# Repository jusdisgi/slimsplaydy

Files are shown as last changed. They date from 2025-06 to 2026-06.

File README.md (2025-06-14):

# Slim Splaydy

This is the real Slim Splaydy. All the other Slim Splaydies are just imitating.

It's a 34-key split ergo layout with a bit of splay and quite a bit of stagger, using Kailh PG1316S ultra-low-profile switches. The result should be extemely slim. I'm using a nice!nano controller, SMD to the board upside down with a cutout for the components, so it chould only be 1.6mm above the PCB surface. The PCB is also cut away where the battery goes, and the case includes a battery holder, allowing up to a 3.0mm battery. The case also has holes for magnets to sit just below the surface, allowing the two sides to magnetically clasp together for transport. When closed up this way the two halves should come in around 8mm thick.

The design is intended to be very easy to assemble. Fvery component on the board is SMD, and all are on the front side. So it should be buildable in one run on a hot plate. Should not even need a soldering iron!

This repo includes the ergogen config file, kicad PCB and schematic files for both left and right halves, and STEP files of all case pieces. Production files and a build guide will follow once everything is finalized.

Here are some pictures...





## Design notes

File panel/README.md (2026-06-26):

# slimsplaydy — JLCPCB panel (KiKit)

Panelize the **routed** slimsplaydy halves for JLCPCB. This is the **scripted** pipeline ported
from LightFury (which proved out the by-hand merge + `kikit fab --assembly` path was a dead end).
The per-half boards (`slimsplaydy_left/right.kicad_pcb`) are the source of truth; everything below
rebuilds the combined board, panel, and CPL/BOM from them, so re-run it any time a half changes.

> **Supersedes** the old "Option B / KiCad *Append Board*" plan and the hand-merged
> `slimsplaydy_both*` files. Don't use those.

Per-half outline ≈ **122.5 × 97.3 mm**. The halves **stack vertically, interlocked** — the lower
half's top peak tucks into the upper half's battery-slot notch — so the nest is much tighter than a
flat side-by-side. Tune `PITCH_MM` / `XOFF_MM` in `merge_both.py` from the first KiKit preview.

**Environment:** use the **KiCad Command Prompt** (so `python` = KiCad's Python with `pcbnew`).
KiKit's `kikit.exe` installs to `...KiCad\9.0\3rdparty\Python311\Scripts`, which isn't on PATH by
default — add it for the session before the `kikit` commands:

```bat
set PATH=%PATH%;C:\Users\hunte\Documents\KiCad\9.0\3rdparty\Python311\Scripts
```

## Full workflow (in order)

```bash
cd slimsplaydy

# 1. Merge the two halves -> slimsplaydy_both.kicad_pcb. Right-half refs get a _2 suffix,
#    nets get L_/R_ prefixes so the halves stay electrically distinct. Vertical interlocked
#    nest, no rotation/tilt (every part is already on a whole degree). Replaces the by-hand
#    merge. ALSO drops 8 kikit:Tab annotations so the panelizer puts tabs exactly where we want.
#    Tune PITCH_MM / XOFF_MM / TAB_ANNOTATIONS in the script from the Step-2 preview.
python panel/merge_both.py

# 2. Frame it into a panel (full frame; tabs come from the annotations, see preset note below).
kikit panelize -p panel/slimsplaydy_panel.json slimsplaydy_both.kicad_pcb panel/slimsplaydy_panel.kicad_pcb

# 3. Export GERBERS from panel/slimsplaydy_panel.kicad_pcb (open in pcbnew -> Fabrication Toolkit
#    plugin, or KiCad Plot). Use the toolkit for GERBERS ONLY — NOT `kikit fab jlcpcb --assembly`
#    (it needs a schematic the panel's _2 refs can't match) and NOT the toolkit's own CPL/BOM.

# 3b. Copy the toolkit's gerber zip up into the canonical order folder:
cp panel/production/slimsplaydy_panel.zip production-panel/

# 4. Generate the CPL + BOM from the SAME panel file, straight into production-panel/.
python panel/gen_cpl.py panel/slimsplaydy_panel.kicad_pcb production-panel

# 5. LOCAL verification — open these and check BEFORE uploading.
python panel/render_cpl.py panel/slimsplaydy_panel.kicad_pcb production-panel/positions.csv panel/verify
#    verify_overview.png : every red dot must sit on a pad cluster, none off-board
#    verify_parts.png    : every red ring at body center; orange star = our pin-1
```

Upload to JLC: the three files in **`../production-panel/`** — `slimsplaydy_panel.zip` +
`positions.csv` + `bom.csv` (and attach `SlimSplaydy_BlindSlot_Both.png` to the order notes).
Full CPL/BOM rules + the one-time JLC rotation pass live in **`CPL_WORKFLOW.md`**.

## Where things live (after cleanup)

- **`../production-panel/`** — the canonical JLC upload set (gerber zip + `bom.csv` + `positions.csv`
  + blind-slot drawing + its own README). **This is what you order from.**
- **`panel/production/`** — Fabrication Toolkit scratch (gitignored, overwritten each run). Not for ordering.
- **`panel/verify/`** — local placement-check PNGs from `render_cpl.py`.
- **`../old_cruft/`** — superseded test-order files (`Production_JLCPCBA/`, the May `production/`,
  retired `cpl_build/`, `REVIEW-KICKOFF.md`). Kept for reference; don't fab from them.

## Parts (what JLC places)

Per half: **17× PG1316S** (S1–S17), **CONN1** Molex Pico-EZmate, **PWR1** power switch, **RST1**
reset switch. LCSC: EZmate `C505023`, power `C2911519`, reset `C79174`, PG1316S **consigned**
`C9900170245`. **Excluded** (not placed): MCU1 nice!nano (**DNP / hand-soldered**), MH1–15 (NPTH
mounting holes), MAG1 (magsafe silk only). `gen_cpl.py` already enforces all of this.

## The one manual step: confirm rotations (do this ONCE)

Positions are exact (origin = body center = JLC datum). The only thing board geometry can't tell us
is how JLC's library part is oriented vs our footprint. Resolve it in a **single clean pass** — read
JLC's exact values, don't nudge:

1. Upload and open JLC's assembly preview.
2. For each **oriented** part — **CONN1** (Molex `C505023`), **PWR1** (`C2911519`), **RST1**
   (`C79174`) — read whether it needs 0/90/180/270°.
3. Put each into `ROT_CORR` in `gen_cpl.py`, keyed by LCSC, then re-run steps 4–5 (positions are
   unaffected) and re-upload. `C79174` = 90 and `C2911519` = 90 are carried over from LightFury (same
   ceoloide footprints) as starting points — **still confirm them**. `C505023` starts at 0
   (un-confirmed). PG1316S (`C9900170245`) starts at 0.

If a part's *body* ever looks off its pads (not just rotated), add `POS_OVERRIDE[lcsc] = (dx, dy)`
in part-local mm. None expected.

## Blind slot (order note — NOT in these files)

The 0.8 mm back pocket for the steel MagSafe ring is **ordered at JLC**, not in the design files —
add it to the order notes / drawing as before
(`Production_JLCPCBA/SlimSplaydy_BlindSlot_Both.png`). At 0.8 mm depth F.Cu is untouched; B.Cu was
hand-routed clear of the ring — keep it clear on any re-route.

## Preset / gotchas

- **`slimsplaydy_panel.json`**: **annotation** tabs + **full frame** + mouse-bites. `fixed`/`spacing`
  tabs distribute blindly and land on the battery-slot openings (and `spacing` errors on concave
  outlines); annotation tabs put a tab exactly at each `kikit:Tab` marker. Rails 5 mm, mouse-bite
  0.5 mm drill @ 0.8 mm, tooling 1.52 mm, fiducials 1 mm copper / 2 mm opening, 1 mm mill radius,
  `JLCJLCJLCJLC` order token, origin `tl`.
- **Tabs are placed by `merge_both.py`** (`UPPER_TABS` + `LOWER_TABS`): **10 tabs, each half held on
  3 sides** — upper: top (2) + right (2) + left (`GreenL`); lower: left (2) + bottom (2) + right
  (`GreenR`). **Every tab is half→frame; there are NO half-to-half tabs** (fewest connections, and
  each cut is cleanly two-sided). They clear both battery slots and flank both MCU slots. Six sit on
  convex bounding-box edges (short tabs); `GreenL`/`GreenR` reach the concave upper-left / lower-right
  edges and are necessarily longer, because KiKit's partition line follows the bounding box.
  `LOWER_TABS` auto-shift with the nest, so they stay on the lower half when you change
  `PITCH_MM`/`XOFF_MM`. To retune: edit a list (each entry is `(x_mm, y_mm, into-board direction
  E/N/W/S)`), re-run step 1, re-preview. **If a tab doesn't appear, flip its direction 180°** — the
  ray pointed the wrong way. You can also drop `kikit:Tab` footprints by hand in KiCad (lib must be
  literally `kikit`; add a text field `KIKIT: width: 3mm`).
- **Don't let KiKit stitch the halves:** KiKit treats `slimsplaydy_both` as ONE board with two
  disjoint outlines and auto-adds a tab joining the two pieces at their single **closest approach**
  (independent of our annotations) — it shows up as a one-sided-cut bridge at the right shoulder of
  the tuck. The fix is separation: **PITCH 85 / XOFF −17** opens the nearest approach to ~6.6 mm
  (right shoulder ~7.6 mm, was 3.5 mm at PITCH 82) so KiKit leaves them apart. Tuck is still ~12 mm.
  (This also clears the **2 mm router** = 2 × `post.millradius` with room to spare.) If KiKit still
  stitches them at this gap, the definitive fix is the **multiboard** route — a `kikit:Board`
  annotation per half so KiKit treats them as two separate boards and never joins them.
- Tune the nest in `merge_both.py`: `PITCH_MM` (vertical center-to-center; smaller = deeper tuck =
  shorter panel, but watch the nearest-approach so KiKit doesn't stitch) and `XOFF_MM` (slide the
  lower half: more negative opens the right shoulder, less negative opens the left). Currently 85 / −17.
- **Prereq (done):** the per-half `LCSC` fields are filled and pushed to the PCBs, so the BOM carries
  part numbers. Verified: `gen_cpl.py` reads `C505023 / C2911519 / C79174 / C9900170245` straight off
  the boards.
- Gerbers and CPL **always** come from the same `slimsplaydy_panel.kicad_pcb` generation. If you
  re-panelize, re-export both — never mix generations.

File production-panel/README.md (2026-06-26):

# SlimSplaydy — JLCPCB order set

**These files are what you upload to JLCPCB. Nothing else.**

| file | what it is | upload as |
|---|---|---|
| `slimsplaydy_panel.zip` | Gerbers + drill for the full panel (both halves, frame, mouse-bites) | Gerber |
| `bom.csv` | Bill of materials (one line per LCSC part) | BOM |
| `positions.csv` | Pick-and-place / CPL (origin datum, integer rotations, PWR offset applied) | CPL |
| `SlimSplaydy_BlindSlot_Both.png` | Drawing for the 0.8 mm blind back-pocket | attach to **order notes** |

The gerber is uploaded once at the **start** of the order (before PCBA). The BOM/CPL are uploaded
in the PCBA step and can be re-uploaded freely. **You only need a fresh gerber when the copper
changes** (re-panelize or a half edit) — pure rotation/position tweaks ride on the CPL alone.

## What JLC assembles vs. what you do by hand

- **Assembled (40 placements):** 34× PG1316S (S1–S17 ×2, **consigned** reel `C9900170245`),
  2× power switch (`C2911519`), 2× reset switch (`C79174`), 2× Molex Pico-EZmate (`C505023`).
- **NOT assembled (mark DNP / hand-solder):** the **nice!nano** (one per half) — not in JLC's
  library. The mounting holes, MAG1 silk, and fiducials are mechanical/markers, not parts.

## Order notes (don't forget)

- **Blind slot:** mill a **0.8 mm-deep back pocket** (B side) under each MagSafe ring per
  `SlimSplaydy_BlindSlot_Both.png`. It is **not** in the gerbers — request it in the order remarks.
- **PG1316S are consigned** (your reel) — declare them as customer-supplied, not JLC-sourced.
- **nice!nano = DNP**, hand-soldered after.

## Regenerating these

Full procedure + hard rules: [`../panel/CPL_WORKFLOW.md`](../panel/CPL_WORKFLOW.md). Short version,
from the repo root, all from the **same** panel generation:

```bat
:: gerbers: open panel\slimsplaydy_panel.kicad_pcb in KiCad, run the Fabrication Toolkit,
:: then copy its zip up here:
copy panel\production\slimsplaydy_panel.zip production-panel\

:: BOM + CPL straight from the same panel file:
python panel\gen_cpl.py panel\slimsplaydy_panel.kicad_pcb production-panel

:: optional local sanity render (writes PNGs to panel\verify\):
python panel\render_cpl.py panel\slimsplaydy_panel.kicad_pcb production-panel\positions.csv panel\verify
```

Gerbers and CPL **must** come from the same panel generation, or parts land on stale copper.

## Part-specific corrections baked into `gen_cpl.py`

- Rotation (`ROT_CORR`) and position (`POS_OVERRIDE`) tweaks for the oriented parts live at the top
  of `gen_cpl.py`. Current: PWR/RST `C2911519`/`C79174` = **90°**, Molex `C505023` = **0°**,
  PG1316S = 0°; PWR `C2911519` nudged **0.3 mm west** (part-local, so the mirrored half tracks it).
- These rotations are confirmed-by-eye in JLC's assembly preview — see the one-time pass in
  `CPL_WORKFLOW.md` if a half edit ever changes a footprint.

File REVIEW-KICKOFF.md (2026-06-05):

# slimsplaydy — review & optimize: session kickoff

Goal: review the **already-routed** slimsplaydy board, fix only genuine functional problems, and get
it panel-ready for JLCPCB. **Preserve the routing.** Regenerating from ergogen wipes routing (forces a
full re-route), so only do it if a real functional defect requires it.

## Context
- 34-key low-profile splay split; nice!nano (one per half), PG1316S. The original "Slim Splaydy".
- **Parent of `../xiphos`** and shares its design concept — read `../xiphos/CLAUDE.md` "Design concept"
  and "Production" sections; the workspace `../CLAUDE.md` "Schematics, combined boards & production"
  section applies here too.
- Already has a **JLC PCBA test order**: `production/` and `Production_JLCPCBA/` (BOM, CPL, gerbers,
  blind-slot drawings). LCSC: EZmate `C505023`, power `C2911519`, reset `C79174`, PG1316S consigned
  `C9900170245`; nano DNP / hand-soldered.
- Files: routed `slimsplaydy_left.kicad_pcb` / `_right` (+ hand-merged `_both*`), `*.kicad_sch`,
  `config.yaml`, local `footprints/`. (Note: `../xiphos/_old_slimsplaydy/` holds copies xiphos forked
  from — the working repo is here.)
- **No `CLAUDE.md` yet** — create one (model on `../zmk-config-totem/CLAUDE.md`; keep it thin) and fold
  in the shared design concept.

## First steps
1. Read `config.yaml`, the routed PCBs, schematics, and the production BOM/CPL. Write `slimsplaydy/CLAUDE.md`.
2. Sanity-check without re-routing: net/ref consistency, BOM completeness (every part has an LCSC #),
   footprints in sync with `../ergogen-footprints`, and schematic ↔ PCB parity per the
   `Schematics_and_Ergogen.md` workflow.
3. **Structure decision:** xiphos moved to a single combined board + one project + `L_`/`R_` nets. For
   slimsplaydy that rework means re-routing — likely **not** worth it since it's routed and PCBA-tested.
   Default to keeping the current structure; unify only if Hunter asks.
4. **Panelize for JLC with KiKit** (multiboard: rails / mouse-bites / fiducials / tooling, nested to
   minimize the bounding rectangle → lower cost). KiKit runs on Hunter's machine; Claude writes the
   config and picks the nest.
5. Confirm the blind-slot fab notes/drawings are current and traces still clear the slot.

git: hands-off — write the commands, don't run them.

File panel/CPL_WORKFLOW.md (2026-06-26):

# SlimSplaydy CPL / BOM workflow

How to produce a correct JLCPCB pick-and-place (CPL) + BOM for the panel. Ported from LightFury,
which debugged this end-to-end; SlimSplaydy is simpler (no LCD, no encoder, no RESW injection).

## The rule set (proven on LightFury, applies here)

- **Position = footprint origin.** The footprint origin sits at each part's body center, which is
  exactly JLC's placement datum. Never shift to the pad centroid — that drags asymmetric parts
  (the Molex, the switches) off their pads.
- **CPL origin = panel Edge.Cuts top-left, Y flipped** — the same frame KiCad/the Fabrication
  Toolkit plots the gerbers in, so CPL and gerbers share one origin **by construction**, no global
  offset.
- **Rotation = footprint orientation + a per-LCSC correction** (`ROT_CORR`), integer degrees.
- **Single source of truth:** CPL + BOM come straight from `panel/slimsplaydy_panel.kicad_pcb` —
  the same file the gerbers come from. Never hand-patch positions.

## The tools (pure Python, no pcbnew — run anywhere)

- `kicad_panel.py` — parses the `.kicad_pcb` (footprints, pads, F.Fab outlines, Edge.Cuts bbox).
- `gen_cpl.py` — writes `positions.csv` + `bom.csv`. Idempotent. `ROT_CORR` / `POS_OVERRIDE` tables
  at the top hold the per-part corrections.
- `render_cpl.py` — draws the placement points over the real copper pads (→ `panel/verify/`) for
  **local** verification before uploading.

## Procedure

Run on the **same** panel file, in lockstep, whenever a half changes:

```bat
cd C:\Users\hunte\Documents\gittyup\slimsplaydy

:: 1. (only if a half changed) re-merge + re-panelize. Needs KiCad's pcbnew + KiKit on PATH.
python panel\merge_both.py
kikit panelize -p panel\slimsplaydy_panel.json slimsplaydy_both.kicad_pcb panel\slimsplaydy_panel.kicad_pcb

:: 2. GERBERS: open panel\slimsplaydy_panel.kicad_pcb in KiCad -> Fabrication Toolkit (-> panel\production\),
::    then copy the zip up into the canonical order folder:
copy panel\production\slimsplaydy_panel.zip production-panel\

:: 3. BOM + CPL from the SAME panel file, straight into production-panel\
python panel\gen_cpl.py panel\slimsplaydy_panel.kicad_pcb production-panel

:: 4. LOCAL verification — render onto the real pads and eyeball before uploading
python panel\render_cpl.py panel\slimsplaydy_panel.kicad_pcb production-panel\positions.csv panel\verify
start panel\verify\verify_overview.png
start panel\verify\verify_parts.png
```

Upload to JLC: the files in **`production-panel\`** — `slimsplaydy_panel.zip` + `positions.csv`
+ `bom.csv` (and attach `SlimSplaydy_BlindSlot_Both.png` to the order notes).

## The one manual step: confirm rotations (do ONCE per footprint change)

Positions are exact; only how JLC's library part is oriented vs our footprint needs a human check.

1. Upload, open JLC's assembly preview.
2. For each oriented part — power SW `C2911519`, reset SW `C79174`, Molex `C505023` — read whether
   it needs 0/90/180/270°. Read JLC's exact value; don't nudge iteratively.
3. Put each into `ROT_CORR` in `gen_cpl.py`, keyed by LCSC; re-run step 3 (positions unaffected).
   Current: `C2911519` = 90, `C79174` = 90 (from LightFury's same ceoloide footprints),
   `C505023` = 0, PG1316S `C9900170245` = 0.

If a part's *body* looks off its pads (not just rotated), add `POS_OVERRIDE[lcsc] = (dx, dy)` in
part-LOCAL mm — it auto-applies to the mirrored half. (PWR `C2911519` already carries a −0.3 mm
local x nudge.)

## Hard rules

- Gerbers and CPL always come from the **same** `slimsplaydy_panel.kicad_pcb` generation. Re-panelize
  → re-export both. No mixing generations.
- The nest (`PITCH_MM` / `XOFF_MM` in `merge_both.py`) must keep the two halves' nearest approach
  apart enough that KiKit doesn't stitch them and the 2 mm router can clear the channel — see the
  note in `merge_both.py`. Current good nest: **PITCH 80 / XOFF −15**.

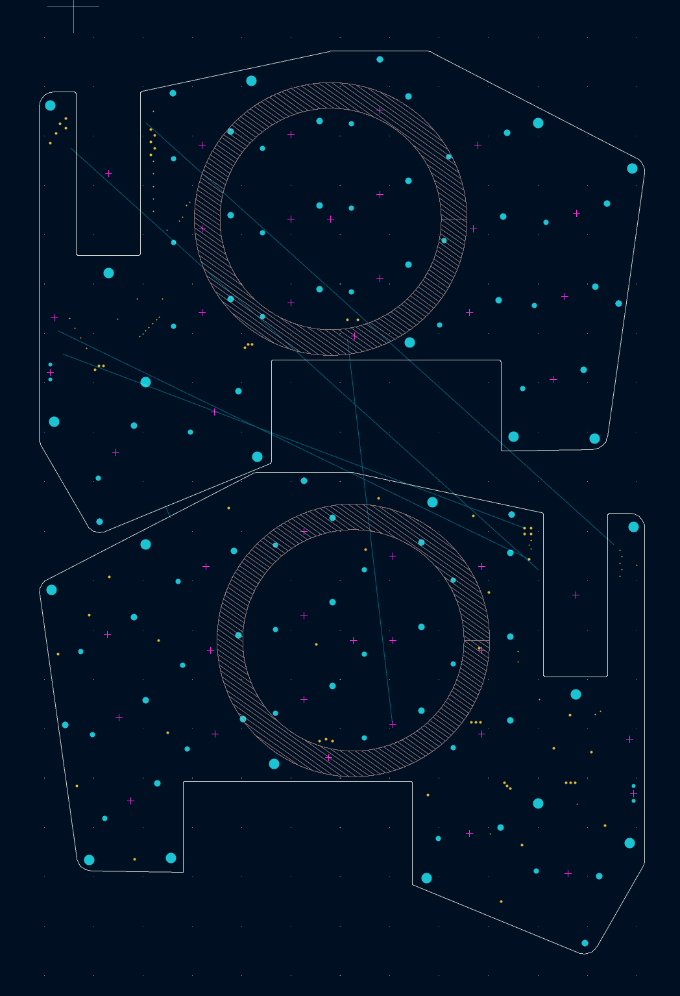
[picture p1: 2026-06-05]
production-panel/SlimSplaydy_BlindSlot_Both.png

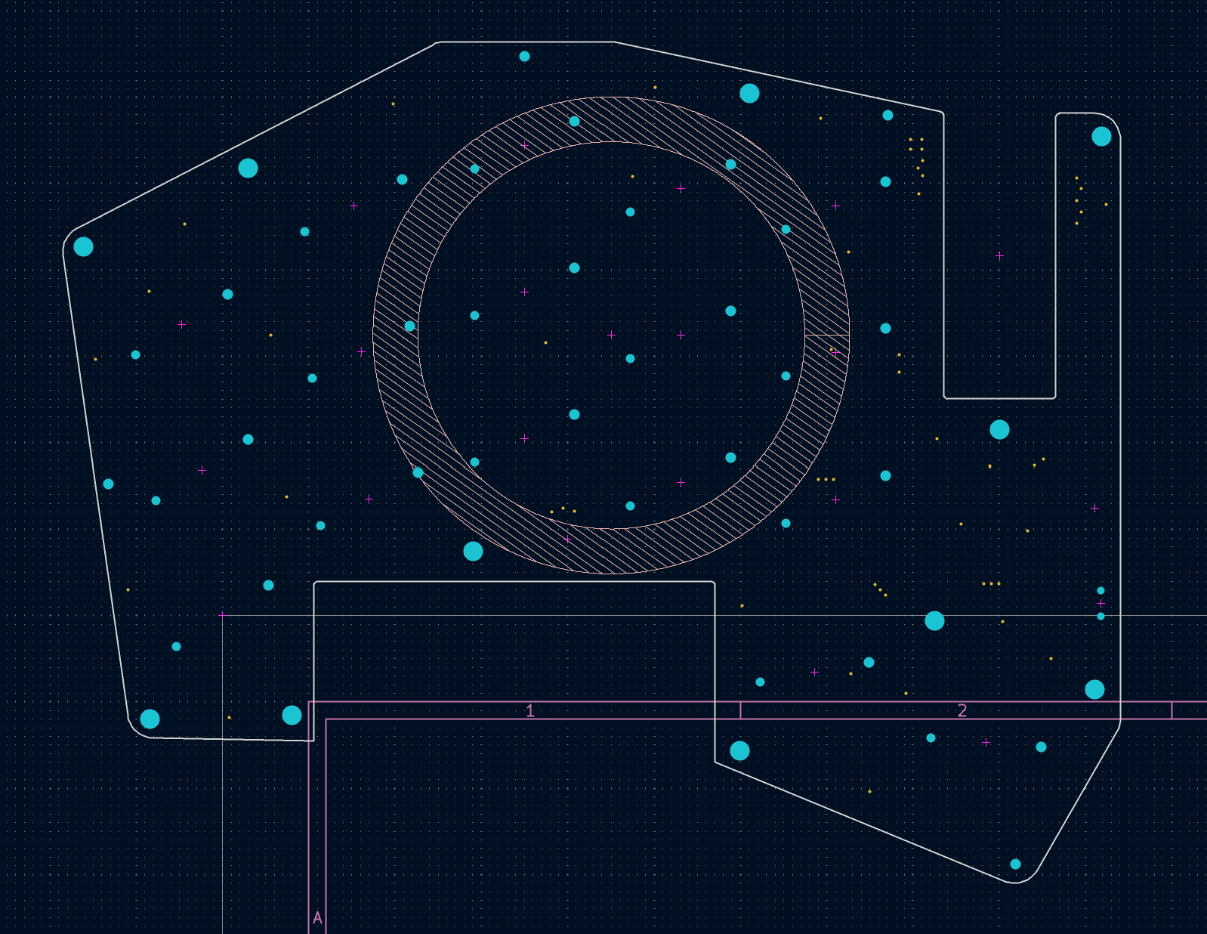
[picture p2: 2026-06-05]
production/SlimSplaydy_BlindSlot_Left.png

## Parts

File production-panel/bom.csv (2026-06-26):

Designator | Footprint | Quantity | Value | LCSC Part #
CONN1, CONN1_2 | Connector_Molex:Molex_Pico-EZmate_78171-0002_1x02-1MP_P1.20mm_Vertical | 2 | Battery Connector | C505023
S1, S10, S10_2, S11, S11_2, S12, S12_2, S13, S13_2, S14, S14_2, S15, S15_2, S16, S16_2, S17, S17_2, S1_2, S2, S2_2, S3, S3_2, S4, S4_2, S5, S5_2, S6, S6_2, S7, S7_2, S8, S8_2, S9, S9_2 | PG1316S | 34 | PG1316S | C9900170245
PWR1, PWR1_2 | ceoloide:power_switch_smd_side | 2 | Power SW | C2911519
RST1, RST1_2 | ceoloide:reset_switch_smd_side | 2 | Reset SW | C79174

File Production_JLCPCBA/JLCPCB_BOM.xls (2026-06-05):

Comment | Designator | Footprint | JLCPCB Part#(optional)
Battery Connector | CONN1,R_CONN1 | Molex_Pico-EZmate_78171-0002_1x02-1MP_P1.20mm_Vertical | C505023
Power Switch | PWR1,R_PWR1 | power_switch_smd_side | C2911519
Reset Switch | RST1,R_RST1 | reset_switch_smd_side | C79174
Keyswitch (Consigned) | S1-17, R_S1-17 | PG1316S | C9900170245

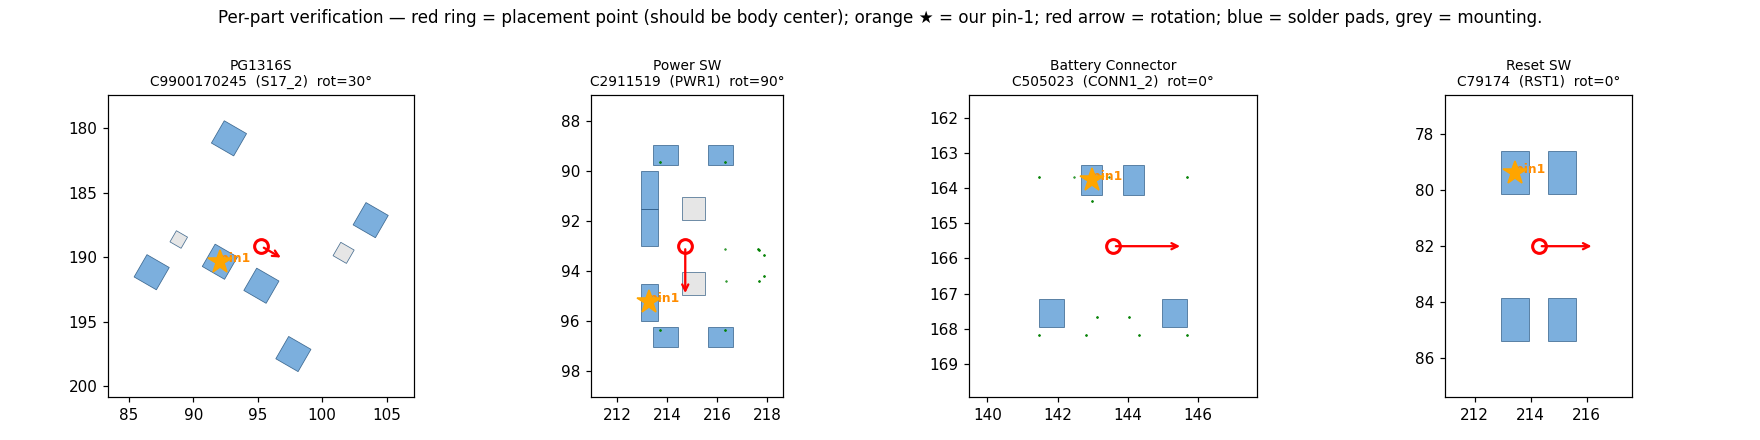
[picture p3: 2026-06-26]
panel/verify/verify_parts.png

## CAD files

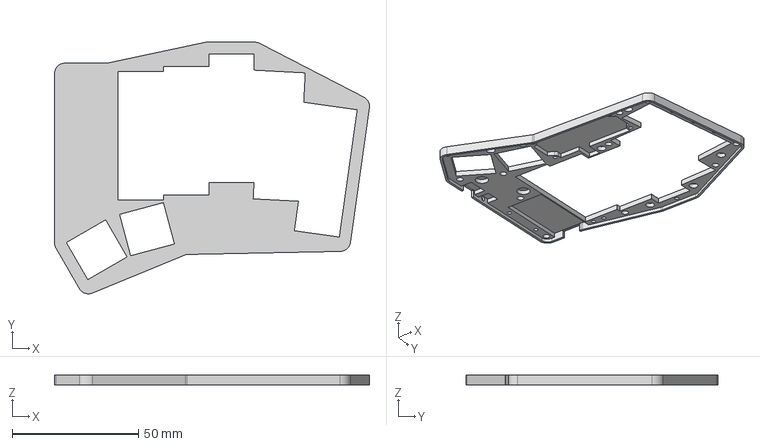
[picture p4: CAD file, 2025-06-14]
Case_Models/SlimSplaydy - Right Side Case.step
125.0 x 99.8 x 4.00 mm

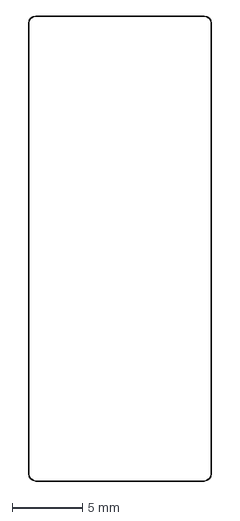
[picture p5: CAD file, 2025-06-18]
output/outlines/mcu_slot_left.dxf
13.0 x 33.1 mm

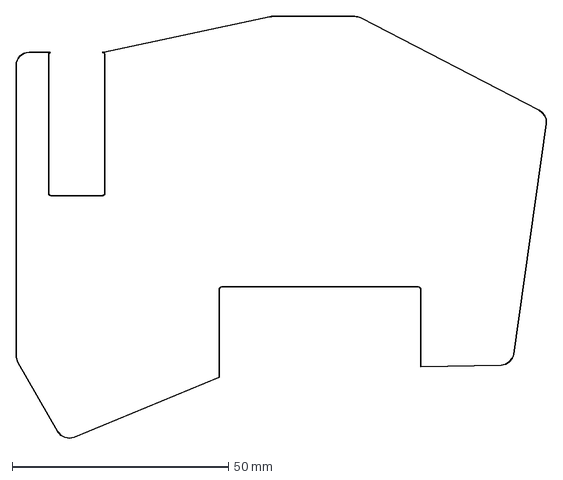
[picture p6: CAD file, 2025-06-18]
output/outlines/board_right.dxf
122.7 x 97.8 mm

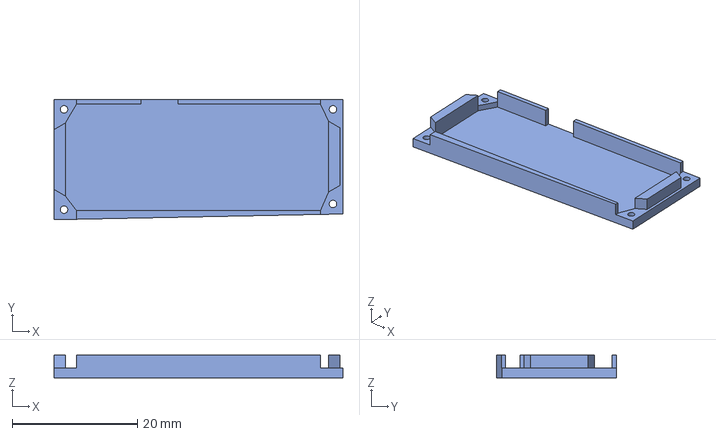
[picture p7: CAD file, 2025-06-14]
Case_Models/SlimSplaydy - Right Battery Holder.step
46.1 x 19.2 x 3.60 mm

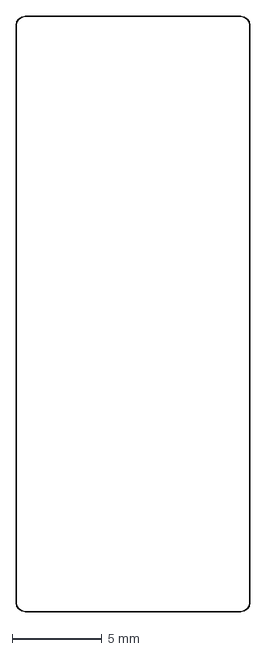
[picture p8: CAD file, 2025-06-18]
output/outlines/mcu_slot_right.dxf
13.0 x 33.1 mm

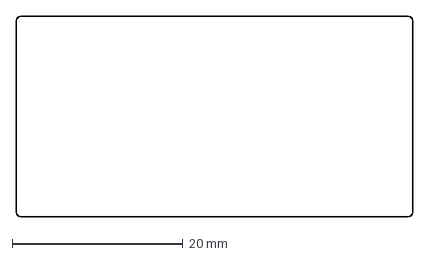
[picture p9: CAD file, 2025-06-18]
output/outlines/batt_slot_right.dxf
46.5 x 23.5 mm

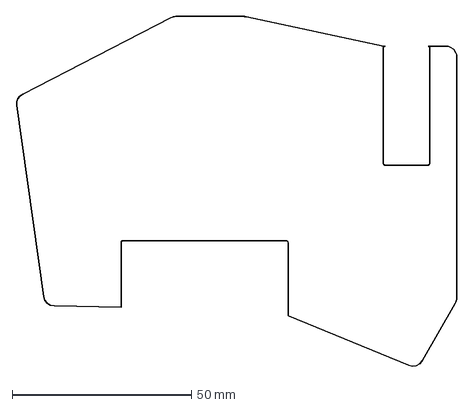
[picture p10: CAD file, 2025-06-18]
output/outlines/board_left.dxf
122.7 x 97.8 mm

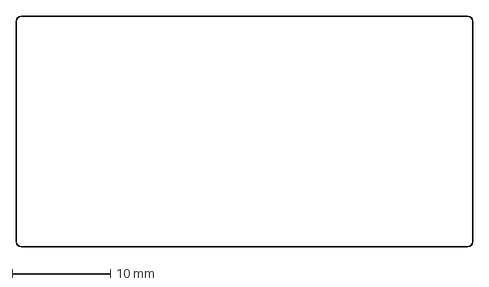
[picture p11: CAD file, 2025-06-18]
output/outlines/batt_slot_left.dxf
46.5 x 23.5 mm

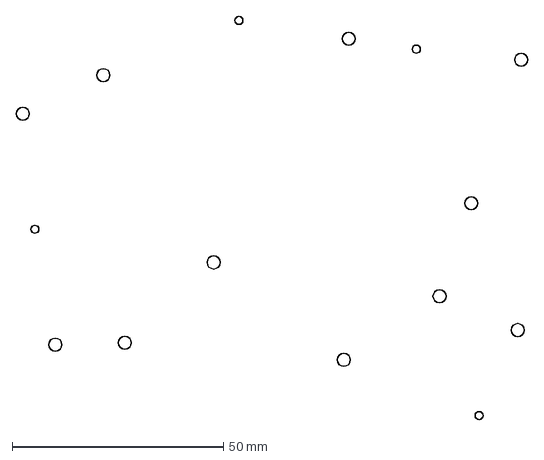
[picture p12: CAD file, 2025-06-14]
output/outlines/nuts.dxf
121.0 x 95.4 mm

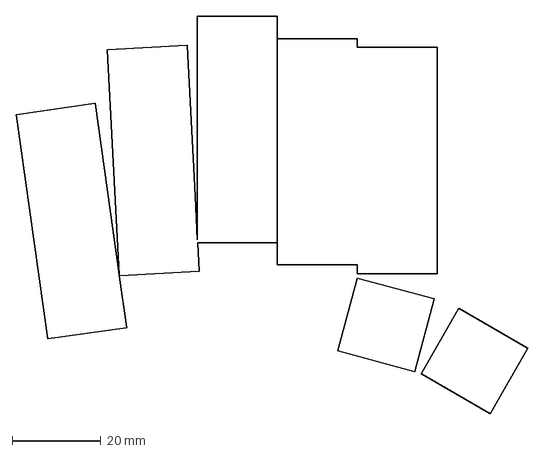
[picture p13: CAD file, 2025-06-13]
output/outlines/case_keycuts_left.dxf
115.4 x 89.5 mm

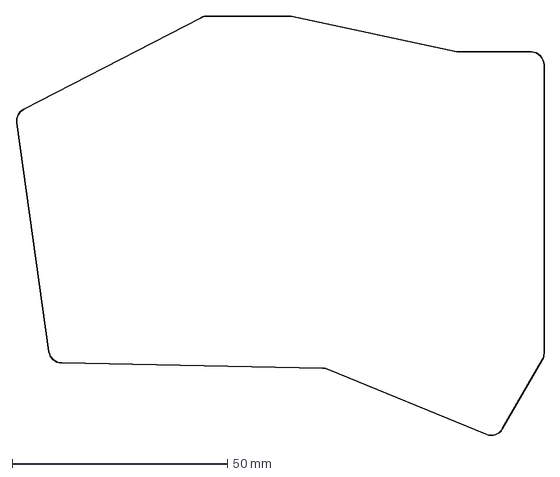
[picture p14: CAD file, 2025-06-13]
output/outlines/shape_left.dxf
122.7 x 97.8 mm

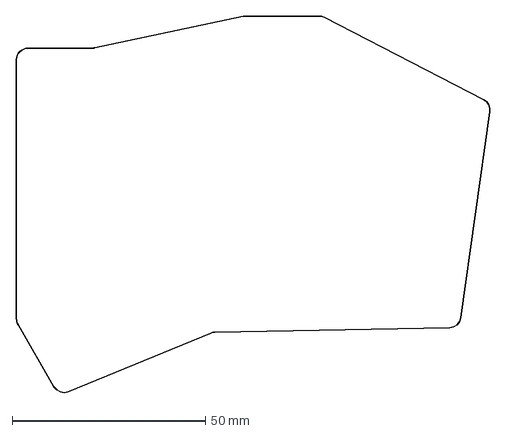
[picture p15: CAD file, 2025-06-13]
output/outlines/shape_right.dxf
122.7 x 97.8 mm

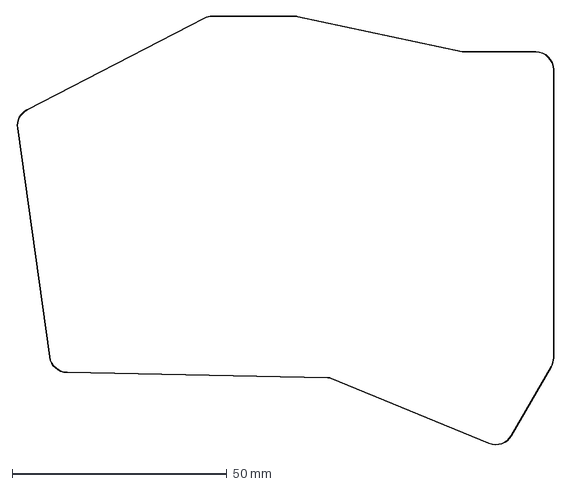
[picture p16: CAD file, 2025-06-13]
output/outlines/case_outer_wall_left.dxf
125.2 x 100.3 mm

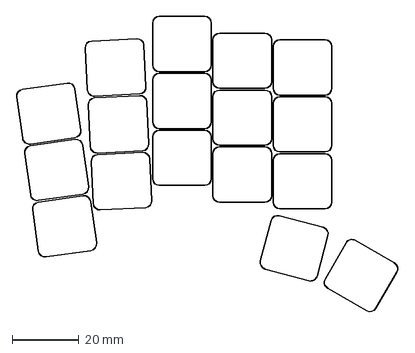
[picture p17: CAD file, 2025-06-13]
output/outlines/keycap_outlines_left.dxf
114.2 x 88.5 mm

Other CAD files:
Case_Models/SlimSplaydy - Left Side Case.step
Case_Models/SlimSplaydy - Left Battery Holder.step
output/outlines/case_inner_wall_left.dxf
output/outlines/screw_heads.dxf
output/outlines/screws.dxf

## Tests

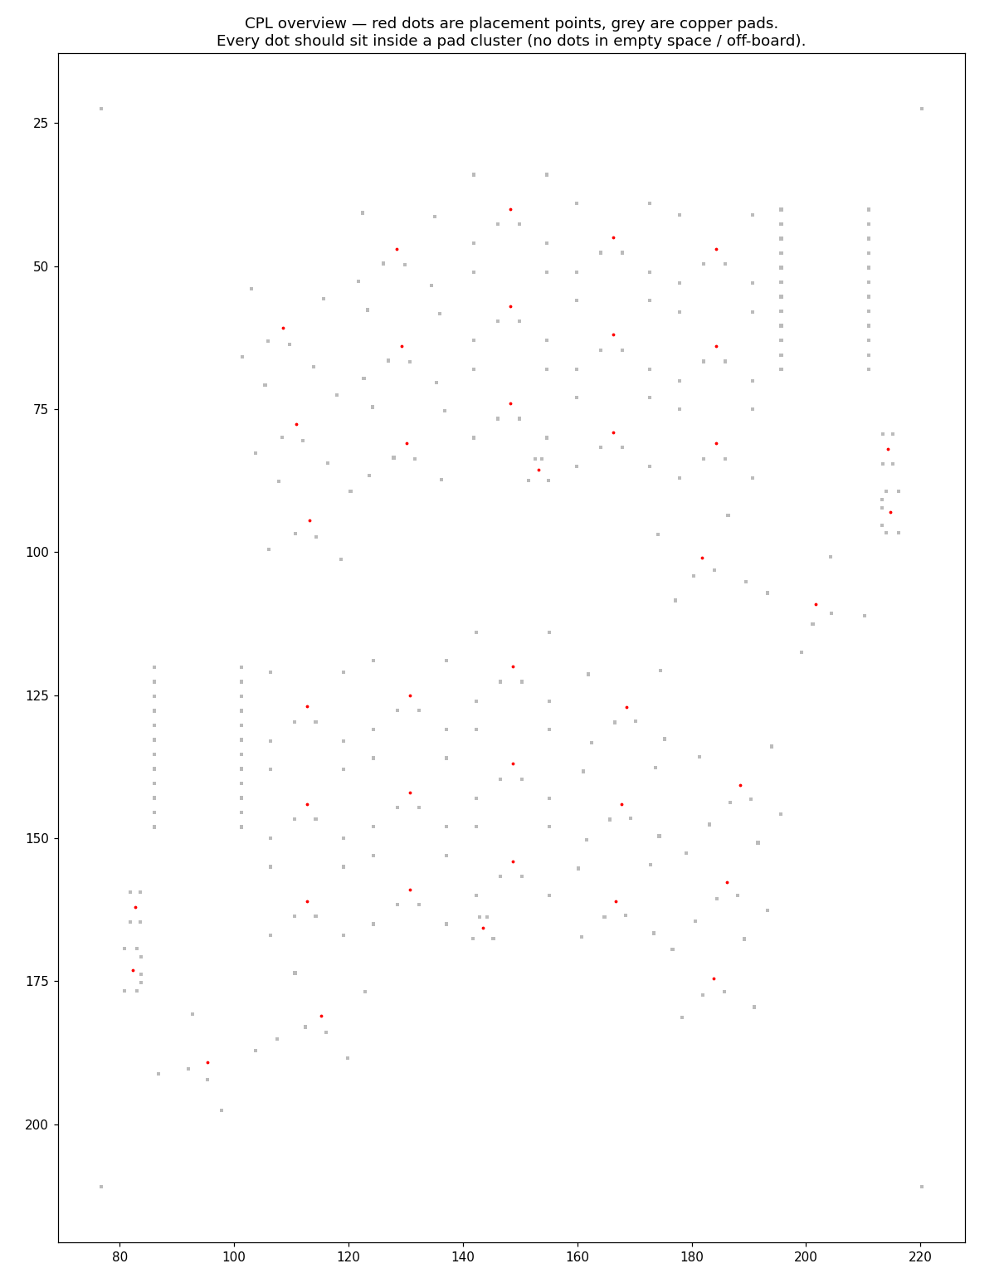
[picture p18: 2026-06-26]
panel/verify/verify_overview.png

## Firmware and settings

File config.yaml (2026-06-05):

meta:
  engine: 4.1.0
  name: SlimSplaydy
  version: 0.1
  ref: &kb_ref "SlimSplaydy v.03"
  author: huntercook
  url: &kb_url https://github.com/jusdisgi/SlimSplaydy
  footprint: &switch_footprint "switch_pg1316s"
  switch:
    $extends: presets.pg1316s
    # Key and keycap measures
    kx: 16
    ky: 16
    ks: 18 # Choc spacing despite the smaller keys
    kp: 17
    keycw: 17.5 # keycap width (cherry: 18, choc: 17.5)
    keych: 16.5 # keycap height (cherry: 18, choc: 16.5)

presets:
  # These presets provide different layout options
  # Select a preset in the `units` section below
  # Note: The appropriate switch footprint will still need to be set in the `pcb` section
  mx:
    # Key and keycap measures
    kx: u # spacing between key centers (X-axis)
    ky: u # spacing between key centers (Y-axis)
    ks: 19 # horizontal space between columns (default: 19)
    kp: 19 # vertical padding between keys (deafult: 19)
    kcow: 14 # key cutout hole width (cherry: 14, choc: 13.8)
    kcoh: 14 # key cutout hole height (cherry: 14, choc: 13.8)
    keycw: 18 # keycap width (cherry: 18, choc: 17.5)
    keych: 18 # keycap height (cherry: 18, choc: 16.5)
    led_pos_x: 0 # Led X position relative to the switch center
    led_pos_y: -4.75 # Led Y position relative to the switch center
    led_rotation: 180 # Led rotation
    vertical_underglow_shift: -0.5 kp # How much to shift underglow leds tied to keys
    vertical_diode_shift: 1.325 # How much to shift to avoid overlap
    horizontal_diode_shift: 7.4
    diode_rotation: 0 # Diode rotation
    switch_rotation: 0 # Hotswap north, led south
  choc_v1:
    # Key and keycap measures
    kx: cx # spacing between key centers (X-axis)
    ky: cy # spacing between key centers (Y-axis)
    ks: 18.5 # horizontal space between columns (default: 19)
    kp: 17.5 # vertical padding between keys (deafult: 19)
    kcow: 13.8 # key cutout hole width (cherry, choc v2: 14, choc v1: 13.8)
    kcoh: 13.8 # key cutout hole height (cherry, choc v2: 14, choc v1: 13.8)
    keycw: 17.5 # keycap width (cherry: 18, choc: 17.5)
    keych: 16.5 # keycap height (cherry: 18, choc: 16.5)
    led_pos_x: 0 # Led X position relative to the switch center
    led_pos_y: 4.7 # Led Y position relative to the switch center
    led_rotation: 0 # Led rotation
    vertical_underglow_shift: -kp + 7.8  # How much to shift underglow leds tied to keys
    vertical_diode_shift: 1.5 # How much to shift to avoid overlap
    horizontal_diode_shift: -0.5 kcow - 0.85
    diode_rotation: -180 # Diode rotation
    switch_rotation: 180 # Hotswap south, led north
  choc_v2:
    # Key and keycap measures
    $extends: presets.choc_v1
    kx: u # spacing between key centers (X-axis)
    ky: u # spacing between key centers (Y-axis)
    ks: 19 # horizontal space between columns (default: 19)
    kp: 19 # vertical padding between keys (deafult: 19)
    keycw: 18 # keycap width (cherry: 18, choc: 17.5)
    keych: 18 # keycap height (cherry: 18, choc: 16.5)
  pg1316s:
    # Key and keycap measures
    kx: 16
    ky: 16
    ks: 17 # typical spacing, for example mikefive uses 17x17
    kp: 17
    kcow: 16 # key cutout hole width (Equal to stock keycaps...caps bottom out by design)
    kcoh: 16 # key cutout hole height (Equal to stock keycaps...caps bottom out by design)
    keycw: 16 # keycap width (cherry: 18, choc: 17.5, stock PG1316S: 16)
    keych: 16 # keycap height (cherry: 18, choc: 16.5, stock PG1316S: 16)
    led_pos_x: 0 # Led X coord from key center. 
    led_pos_y: 2.5 # Led Y coord from key center. 2.5 is center of the slot.
    led_rotation: 0 # Led rotation
    vertical_underglow_shift: -0.5 kp  # How much to shift underglow leds tied to keys
    vertical_diode_shift: 1.5 # How much to shift to avoid overlap
    horizontal_diode_shift: -0.5 kcow - 0.85
    diode_rotation: 0 # Diode rotation
    switch_rotation: 0 #LED north
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

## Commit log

2025-05-09 Create scaffolding for new design in ergogen including nicenano, new outline, diode delete, new key sp acing.
    [board_left.dxf, board_right.dxf, combo.dxf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]
2025-05-09 Add battery footprint, change outline.
    [board_left.dxf, board_right.dxf, combo.dxf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]
2025-05-10 Complete left-side, at least to first-draft levels.
    [bom.csv, combo.dxf, designators.csv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]
2025-05-11 Create first draft design and routing for both sides.
    [board_left.dxf, board_right.dxf, combo_left.dxf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]
2025-05-20 Add new reversable PG1316S footprint.
    [slimsplaydy_left_unrouted.kicad_pcb, slimsplaydy_right_unrouted.kicad_pcb, slimsplaydy_unrouted.kicad_pcb]
2025-05-21 Add configuraton options for pads in PG1316S footprint.
    [slimsplaydy_left_unrouted.kicad_pcb]
2025-05-21 Move dev version of PG1316S footprint onto main file.
2025-05-21 Change weird 5/28 roundrect ratios to 1/8
    [slimsplaydy_left_unrouted.kicad_pcb, slimsplaydy_right_unrouted.kicad_pcb, slimsplaydy_unrouted.kicad_pcb]
2025-05-21 Add via placement options to PG1316S footprint.
    [slimsplaydy_left_unrouted.kicad_pcb]
2025-05-21 Add logic to only place vias once when board is reversible; fix mispellings of reversible.
    [bigbottom_left.stl, bottom_left.stl, bottom_right.stl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]
2025-05-23 Reposition battery/connector, work on mounting holes.
    [board_left.dxf, board_right.dxf, bom.csv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]
2025-05-23 Make 3D model variable names consistent with ceoloide footprints.
2025-05-28 Finish up mounting, add case outlines, export step.
    [board_left.dxf, board_right.dxf, case_edge_left.dxf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]
2025-05-30 Fix bug in PG1316S footprint causing vias in pads to not route correctly.
    [bigbottom_left.stl, board_left.dxf, board_right.dxf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]
2025-05-30 Add via holesize options separate from via size options.
    [slimsplaydy_left_unrouted.kicad_pcb, slimsplaydy_right_unrouted.kicad_pcb]
2025-06-02 Change edge cuts to drill holes for mounting legs on PG1316S footprint.
2025-06-13 Finish layout, schematic, routing.
    [batt_slot_left.dxf, batt_slot_right.dxf, board_left.dxf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]
2025-06-13 First draft routing for right side. Reeeeaaally ugly.
    [slimsplaydy_right.kicad_pcb]
2025-06-14 Fix MCU slots. Fillet outline. Reroute both sides. Re-re-reroute both sides.
    [board_left.dxf, board_right.dxf, case_edge_left.dxf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]
2025-06-14 Add case STEP files.
    [SlimSplaydy - Left Battery Holder.step, SlimSplaydy - Left Side Case.step, SlimSplaydy - Right Battery Holder.step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]
2025-06-18 Add production files.
    [batt_slot_left.dxf, batt_slot_right.dxf, board_left.dxf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]
2026-06-05 Cleanup ergogen and other from ezmate 1.0mm -> 1.2mm swap
    [JLCPCB_BOM.xls, bom.csv, designators.csv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]
2026-06-05 Added LCSC fields to all parts.
    [slimsplaydy_both.kicad_pcb, slimsplaydy_both_c.kicad_pcb, slimsplaydy_both_close.kicad_pcb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]
2026-06-05 Fix nice_nano symbol so pins are power driven.
    [slimsplaydy_left.kicad_pcb, slimsplaydy_left.kicad_sch, slimsplaydy_right.kicad_pcb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]
2026-06-19 Add panelizer and bom/cpl setup scripts.
2026-06-20 Work on panel
    [slimsplaydy_both.kicad_pcb, slimsplaydy_panel.kicad_pcb]
2026-06-20 Complete panel.
    [slimsplaydy_both.kicad_pcb, slimsplaydy_panel.kicad_pcb]
2026-06-26 Fix missing screenprinting in Magsafe footprint
    [JLCPCB_BOM.xls, bom.csv, designators.csv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]
2026-06-26 Add new production file with magsafe silkscreen fix.

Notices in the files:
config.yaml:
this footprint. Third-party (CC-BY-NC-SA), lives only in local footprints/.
